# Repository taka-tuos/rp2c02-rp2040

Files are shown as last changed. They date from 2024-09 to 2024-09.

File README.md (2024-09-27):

# RP2C02 & RP2040 DevBoard

## 概要
RP2C02の限界が見たかったので作った

## 写真
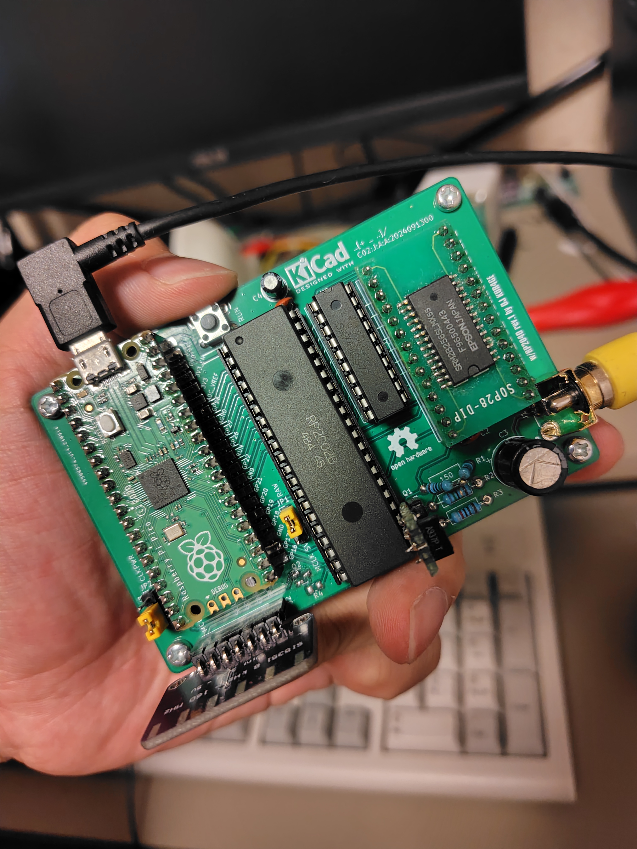
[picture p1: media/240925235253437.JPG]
Rev.1.0


## 部品
- 1 x Raspberry Pi Pico
- 1 x RP2C02
- 1 x Si5351Aモジュール(Adafruitタイプ、25MHz) or ピン互換の21.477272MHzモジュール(各自で作成)
- 1 x 2SA937
- 1 x 74HC573
- 1 x 62256 (<120ns)
- 2 x 100nF 2.54mm
- 1 x 22uF 5.0φ
- 1 x 470uF
- 1 x 150ohm
- 1 x 75ohm
- 1 x 820ohm
- 1 x RCAコネクタ

## なんでRP2040？
手元にあったのと流行りなので…

## レベル変換は？
- ADCピン以外は5.0Vまで耐えられるらしいので、それを信じることにした
- WRITEだけなら問題ない(割り込みピンはOpen-Drain駆動)

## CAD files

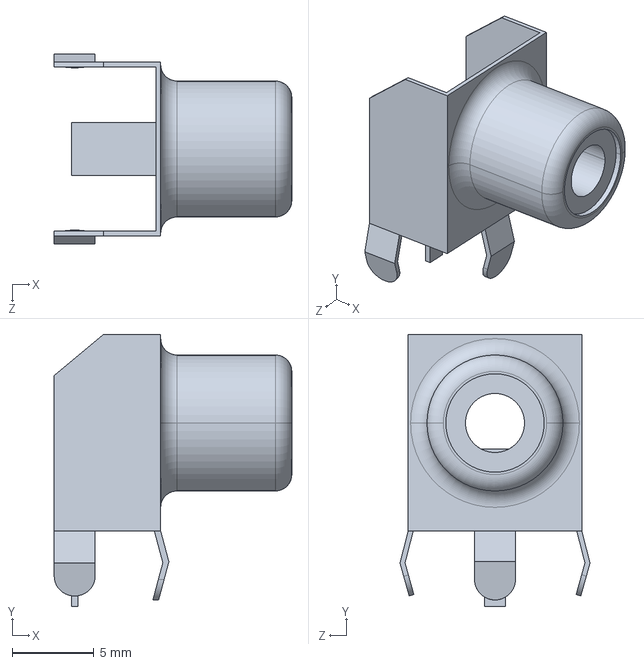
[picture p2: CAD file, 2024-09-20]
rp2c02-rp2040-withlevelshift/CUI_DEVICES_RCJ-014.step
14.5 x 16.6 x 11.6 mm

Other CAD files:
rp2c02-rp2040-withlevelshift/CUI_DEVICES_RCJ-014.igs

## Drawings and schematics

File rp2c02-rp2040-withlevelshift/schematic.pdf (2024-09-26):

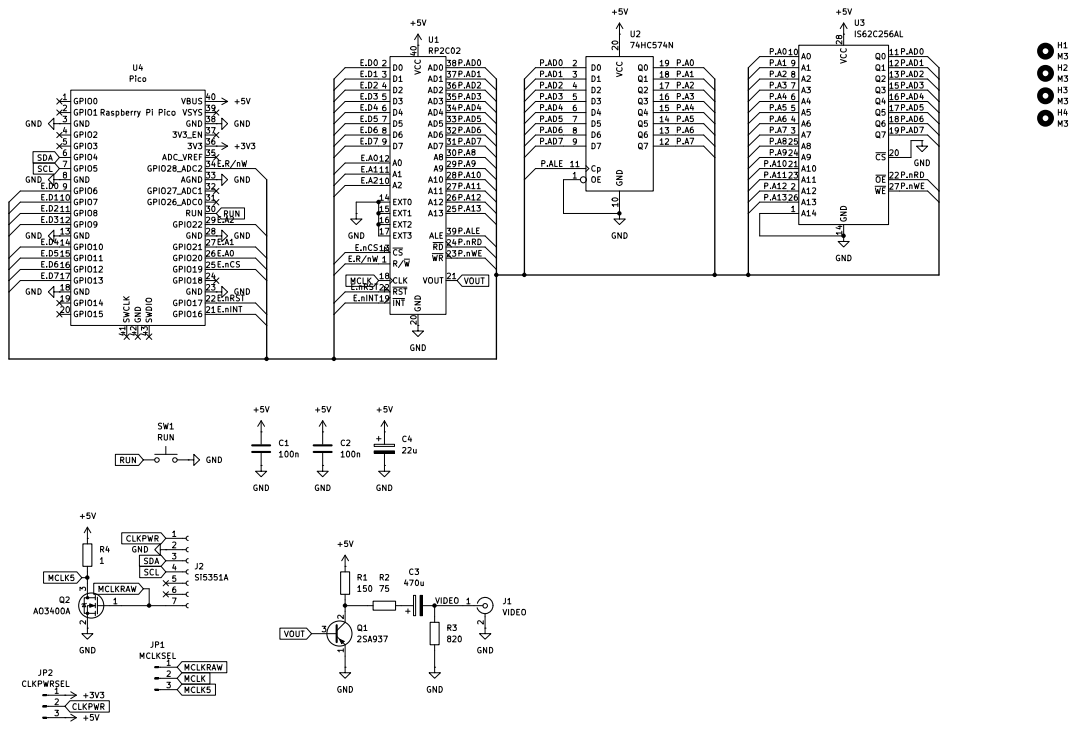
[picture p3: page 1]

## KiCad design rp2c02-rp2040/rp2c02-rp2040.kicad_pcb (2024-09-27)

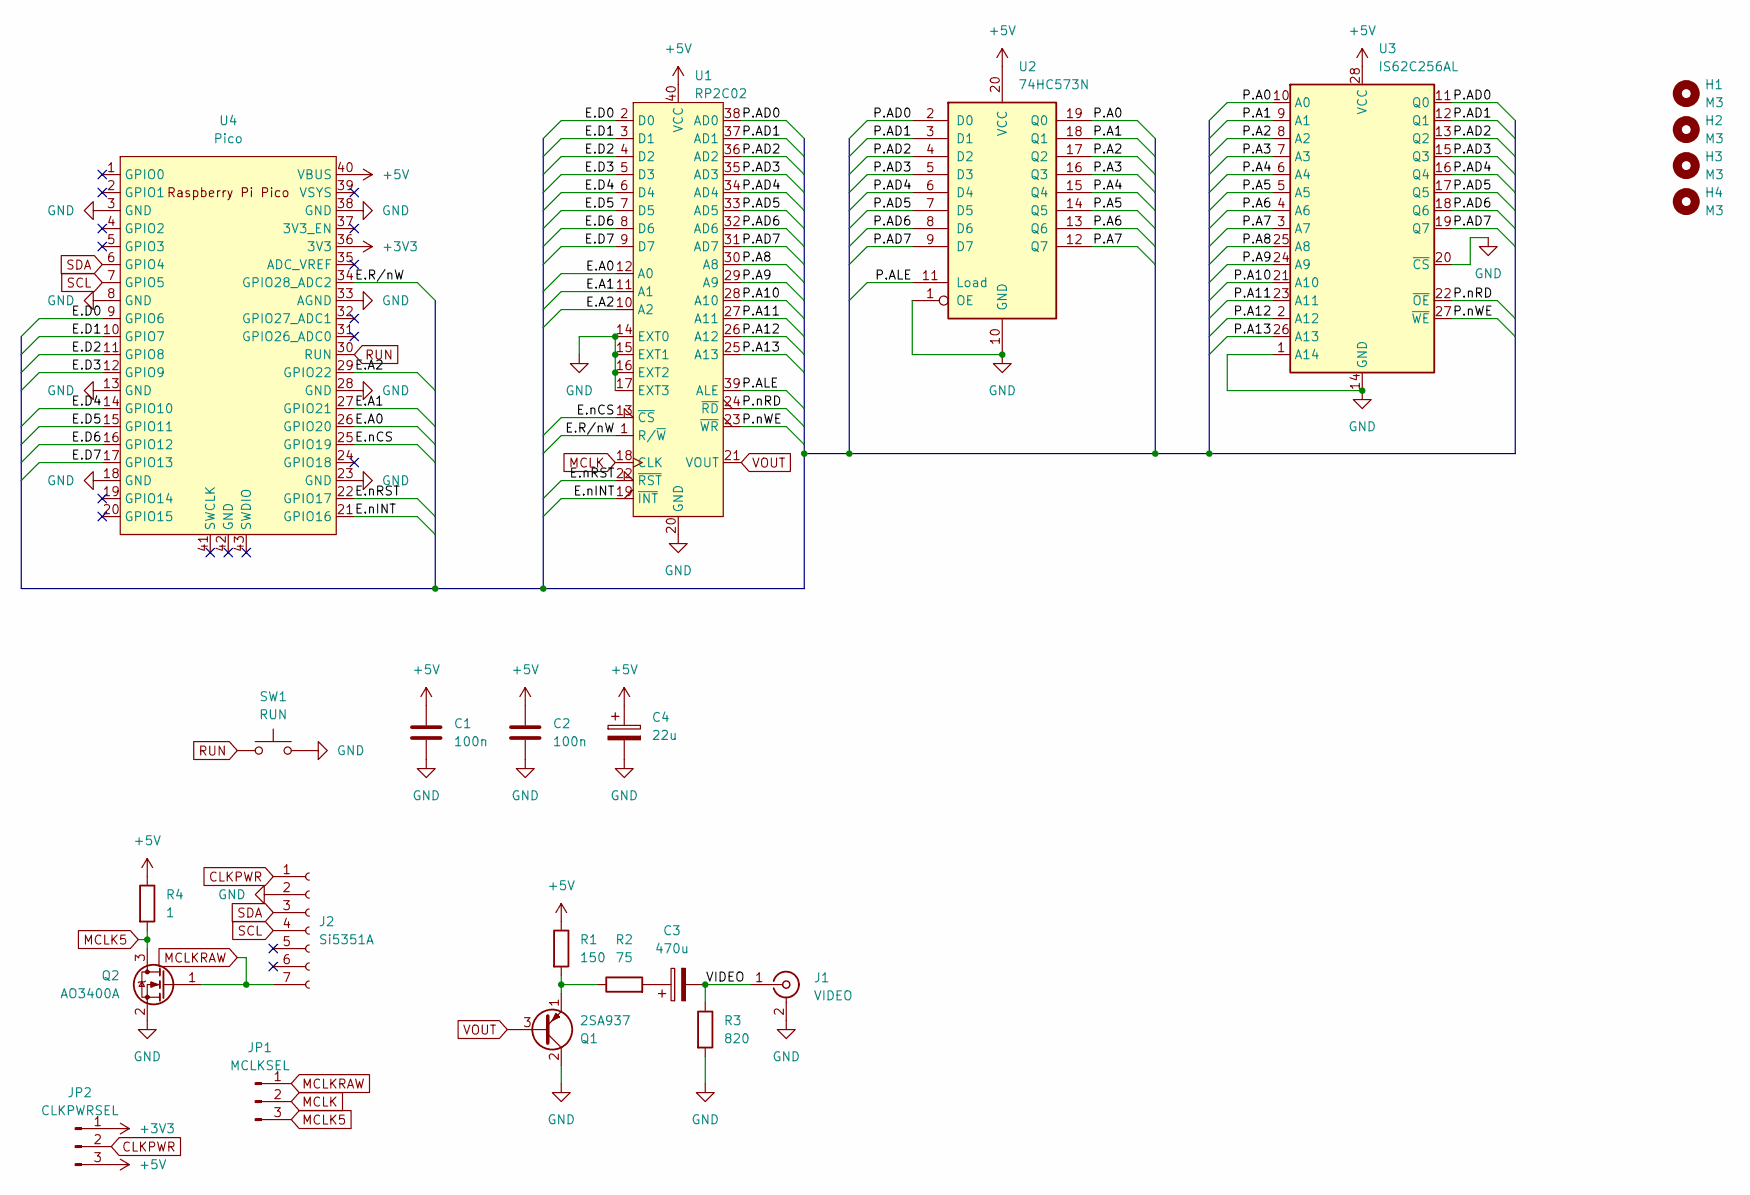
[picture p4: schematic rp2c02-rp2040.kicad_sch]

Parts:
C1, C2: 100n; C_Disc_D3.0mm_W1.6mm_P2.50mm
C3: 470u; CP_Radial_D10.0mm_P5.00mm
C4: 22u; CP_Radial_D5.0mm_P2.00mm
H1, H2, H3, H4: M3; MountingHole_3.2mm_M3
J1: VIDEO; CUI_RCJ-014
J2: Si5351A; PinSocket_1x07_P2.54mm_Vertical
JP1: MCLKSEL; PinHeader_1x03_P2.54mm_Vertical
JP2: CLKPWRSEL; PinHeader_1x03_P2.54mm_Vertical
Q1: 2SA937; PinSocket_1x03_P2.54mm_Vertical
Q2: AO3400A; SOT-23
R1: 150; R_Axial_DIN0207_L6.3mm_D2.5mm_P10.16mm_Horizontal
R2: 75; R_Axial_DIN0207_L6.3mm_D2.5mm_P10.16mm_Horizontal
R3: 820; R_Axial_DIN0207_L6.3mm_D2.5mm_P10.16mm_Horizontal
R4: 1; R_0805_2012Metric_Pad1.20x1.40mm_HandSolder
SW1: RUN; SW_PUSH_6mm
U1: RP2C02; DIP-40_W15.24mm_Socket
U2: 74HC573N; DIP-20_W7.62mm_Socket
U3: IS62C256AL; DIP-28_W15.24mm_Socket
U4: Pico; RPi_Pico_SMD_TH

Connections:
+3V3: JP2.1, U4.36 (3V3)
+5V: C1.1, C2.1, C4.1, JP2.3, R1.1, R4.1, U1.40 (VCC), U2.20 (VCC), U3.28 (VCC), U4.40 (VBUS)
/E.A0: U1.12 (A0), U4.26 (GPIO20)
/E.A1: U1.11 (A1), U4.27 (GPIO21)
/E.A2: U1.10 (A2), U4.29 (GPIO22)
/E.D0: U1.2 (D0), U4.9 (GPIO6)
/E.D1: U1.3 (D1), U4.10 (GPIO7)
/E.D2: U1.4 (D2), U4.11 (GPIO8)
/E.D3: U1.5 (D3), U4.12 (GPIO9)
/E.D4: U1.6 (D4), U4.14 (GPIO10)
/E.D5: U1.7 (D5), U4.15 (GPIO11)
/E.D6: U1.8 (D6), U4.16 (GPIO12)
/E.D7: U1.9 (D7), U4.17 (GPIO13)
/E.R/nW: U1.1 (R/~W), U4.34 (GPIO28_ADC2)
/E.nCS: U1.13 (~CS), U4.25 (GPIO19)
/E.nINT: U1.19 (~INT), U4.21 (GPIO16)
/E.nRST: U1.22 (~RST), U4.22 (GPIO17)
/P.A0: U2.19 (Q0), U3.10 (A0)
/P.A1: U2.18 (Q1), U3.9 (A1)
/P.A2: U2.17 (Q2), U3.8 (A2)
/P.A3: U2.16 (Q3), U3.7 (A3)
/P.A4: U2.15 (Q4), U3.6 (A4)
/P.A5: U2.14 (Q5), U3.5 (A5)
/P.A6: U2.13 (Q6), U3.4 (A6)
/P.A7: U2.12 (Q7), U3.3 (A7)
/P.A8: U1.30 (A8), U3.25 (A8)
/P.A9: U1.29 (A9), U3.24 (A9)
/P.A10: U1.28 (A10), U3.21 (A10)
/P.A11: U1.27 (A11), U3.23 (A11)
/P.A12: U1.26 (A12), U3.2 (A12)
/P.A13: U1.25 (A13), U3.26 (A13)
/P.AD0: U1.38 (AD0), U2.2 (D0), U3.11 (Q0)
/P.AD1: U1.37 (AD1), U2.3 (D1), U3.12 (Q1)
/P.AD2: U1.36 (AD2), U2.4 (D2), U3.13 (Q2)
/P.AD3: U1.35 (AD3), U2.5 (D3), U3.15 (Q3)
/P.AD4: U1.34 (AD4), U2.6 (D4), U3.16 (Q4)
/P.AD5: U1.33 (AD5), U2.7 (D5), U3.17 (Q5)
/P.AD6: U1.32 (AD6), U2.8 (D6), U3.18 (Q6)
/P.AD7: U1.31 (AD7), U2.9 (D7), U3.19 (Q7)
/P.ALE: U1.39 (ALE), U2.11 (Load)
/P.nRD: U1.24 (~RD), U3.22 (~OE)
/P.nWE: U1.23 (~WR), U3.27 (~WE)
/VIDEO: C3.2, J1.1 (In), R3.1
CLKPWR: J2.1, JP2.2
GND: C1.2, C2.2, C4.2, J1.2 (Ext), J2.2, Q1.2 (C), Q2.2 (S), R3.2, SW1.2, U1.14 (EXT0), U1.15 (EXT1), U1.16 (EXT2), U1.17 (EXT3), U1.20 (GND), U2.1 (OE), U2.10 (GND), U3.1 (A14), U3.14 (GND), U3.20 (~CS), U4.3 (GND), U4.8 (GND), U4.13 (GND), U4.18 (GND), U4.23 (GND), U4.28 (GND), U4.33 (AGND), U4.38 (GND)
MCLK: JP1.2, U1.18 (CLK)
MCLK5: JP1.3, Q2.3 (D), R4.2
MCLKRAW: J2.7, JP1.1, Q2.1 (G)
unnamed: C3.1, R2.2
unnamed: Q1.1 (E), R1.2, R2.1
RUN: SW1.1, U4.30 (RUN)
SCL: J2.4, U4.7 (GPIO5)
SDA: J2.3, U4.6 (GPIO4)
VOUT: Q1.3 (B), U1.21 (VOUT)

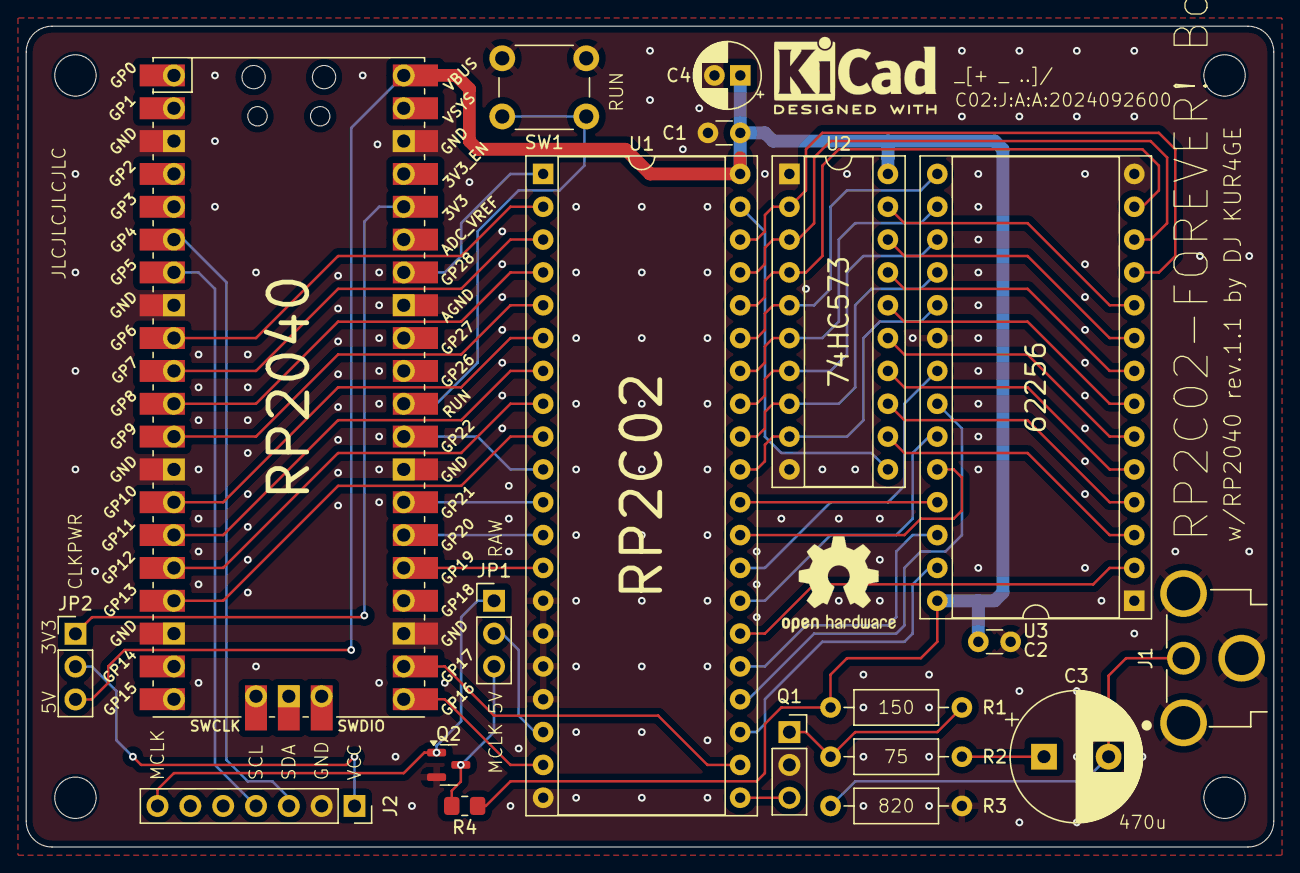
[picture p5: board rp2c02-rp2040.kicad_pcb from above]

Board: 2 copper layers, 96.5 x 63.5 mm, 23 parts (0 on the bottom side), 54 nets.

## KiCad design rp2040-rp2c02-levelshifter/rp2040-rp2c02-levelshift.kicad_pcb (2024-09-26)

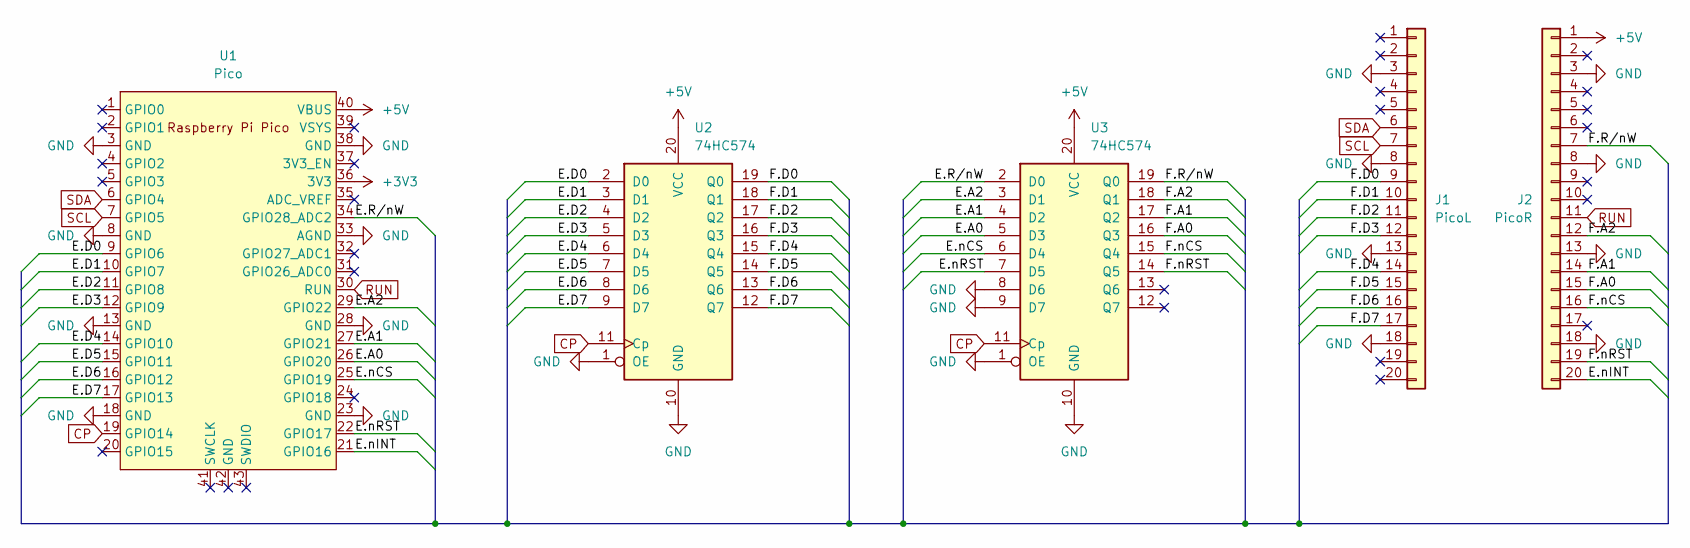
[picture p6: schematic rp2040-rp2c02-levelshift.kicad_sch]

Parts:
J1: PicoL; PinHeader_1x20_P2.54mm_Vertical
J2: PicoR; PinHeader_1x20_P2.54mm_Vertical
U1: Pico; RPi_Pico_SMD_TH
U2, U3: 74HC574; DIP-20_W7.62mm_Socket

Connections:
+3V3: U1.36 (3V3)
+5V: J2.1, U1.40 (VBUS), U2.20 (VCC), U3.20 (VCC)
/E.A0: U1.26 (GPIO20), U3.5 (D3)
/E.A1: U1.27 (GPIO21), U3.4 (D2)
/E.A2: U1.29 (GPIO22), U3.3 (D1)
/E.D0: U1.9 (GPIO6), U2.2 (D0)
/E.D1: U1.10 (GPIO7), U2.3 (D1)
/E.D2: U1.11 (GPIO8), U2.4 (D2)
/E.D3: U1.12 (GPIO9), U2.5 (D3)
/E.D4: U1.14 (GPIO10), U2.6 (D4)
/E.D5: U1.15 (GPIO11), U2.7 (D5)
/E.D6: U1.16 (GPIO12), U2.8 (D6)
/E.D7: U1.17 (GPIO13), U2.9 (D7)
/E.R/nW: U1.34 (GPIO28_ADC2), U3.2 (D0)
/E.nCS: U1.25 (GPIO19), U3.6 (D4)
/E.nINT: J2.20, U1.21 (GPIO16)
/E.nRST: U1.22 (GPIO17), U3.7 (D5)
/F.A0: J2.15, U3.16 (Q3)
/F.A1: J2.14, U3.17 (Q2)
/F.A2: J2.12, U3.18 (Q1)
/F.D0: J1.9, U2.19 (Q0)
/F.D1: J1.10, U2.18 (Q1)
/F.D2: J1.11, U2.17 (Q2)
/F.D3: J1.12, U2.16 (Q3)
/F.D4: J1.14, U2.15 (Q4)
/F.D5: J1.15, U2.14 (Q5)
/F.D6: J1.16, U2.13 (Q6)
/F.D7: J1.17, U2.12 (Q7)
/F.R/nW: J2.7, U3.19 (Q0)
/F.nCS: J2.16, U3.15 (Q4)
/F.nRST: J2.19, U3.14 (Q5)
CP: U1.19 (GPIO14), U2.11 (Cp), U3.11 (Cp)
GND: J1.3, J1.8, J1.13, J1.18, J2.3, J2.8, J2.13, J2.18, U1.3 (GND), U1.8 (GND), U1.13 (GND), U1.18 (GND), U1.23 (GND), U1.28 (GND), U1.33 (AGND), U1.38 (GND), U2.1 (OE), U2.10 (GND), U3.1 (OE), U3.8 (D6), U3.9 (D7), U3.10 (GND)
RUN: J2.11, U1.30 (RUN)
SCL: J1.7, U1.7 (GPIO5)
SDA: J1.6, U1.6 (GPIO4)

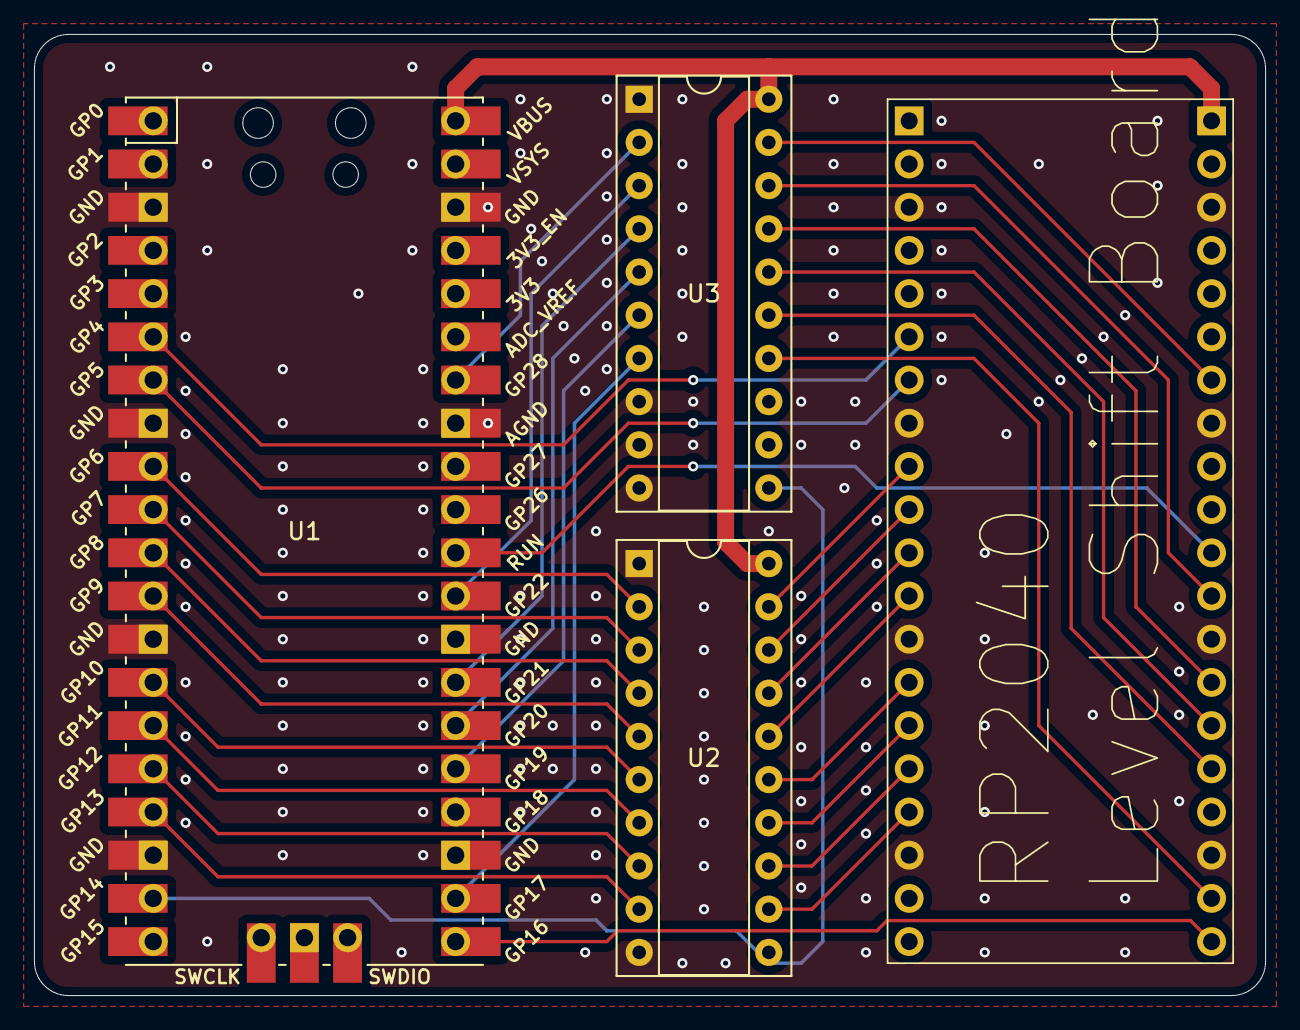
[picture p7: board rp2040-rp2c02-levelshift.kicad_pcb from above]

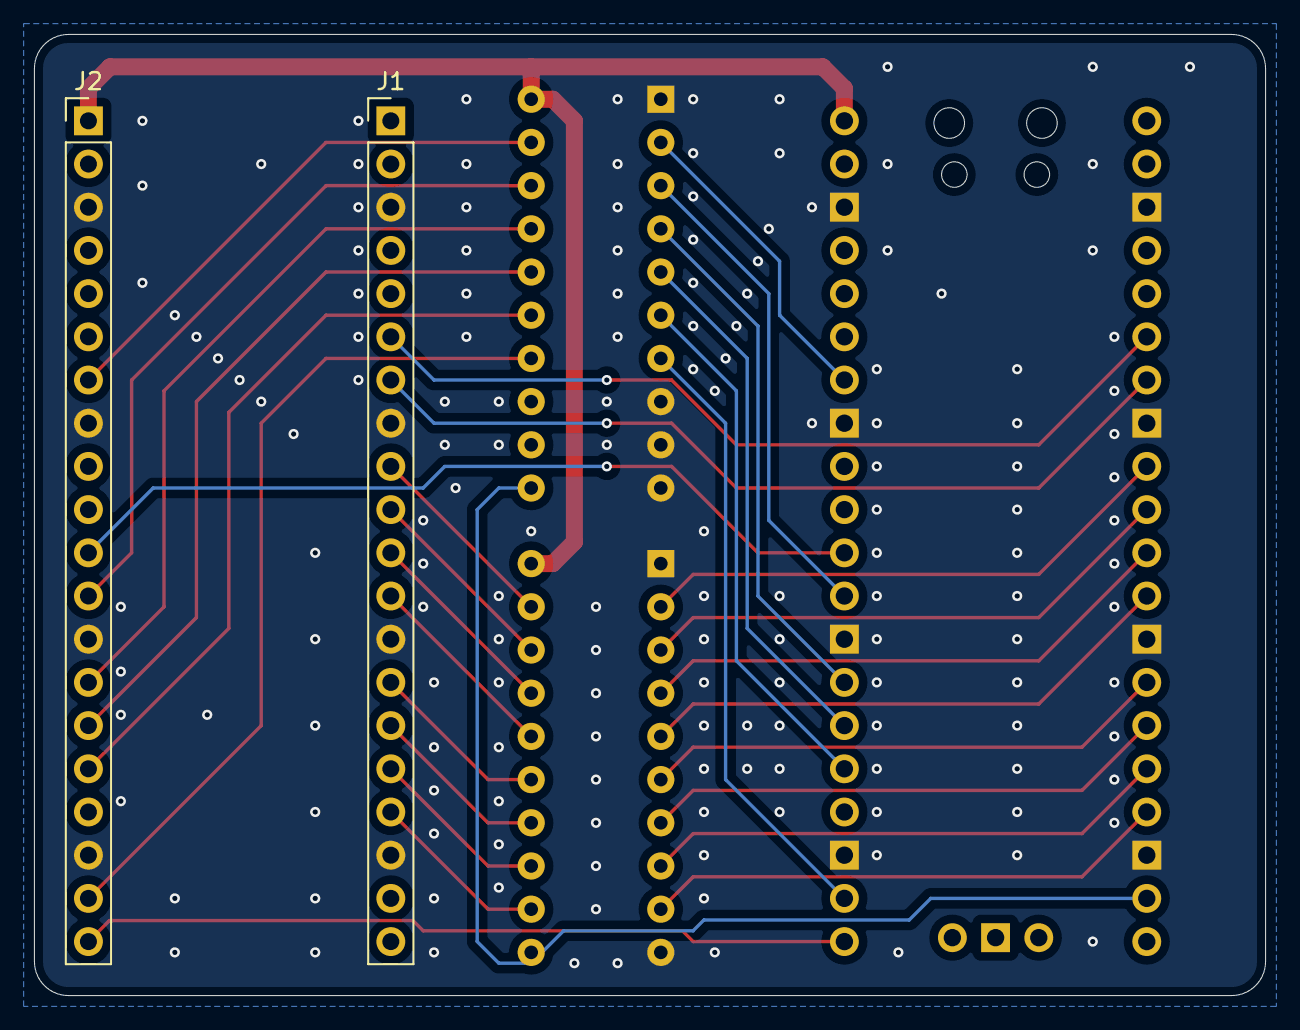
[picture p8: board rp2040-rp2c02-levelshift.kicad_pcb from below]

Board: 2 copper layers, 72.4 x 56.5 mm, 5 parts (2 on the bottom side), 35 nets.

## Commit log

2024-09-20 READMEとライセンスを追加
2024-09-26 レベルシフト版/レベルシフト基板追加、通常基板の2SA937ピン逆転修正
    [CUI_DEVICES_RCJ-014.igs, CUI_DEVICES_RCJ-014.step, rp2040-rp2c02-levelshift.kicad_pcb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]
2024-09-27 74HC573に修正
    [rp2c02-rp2040.kicad_pcb, rp2c02-rp2040.kicad_sch]
2024-09-27 README更新
